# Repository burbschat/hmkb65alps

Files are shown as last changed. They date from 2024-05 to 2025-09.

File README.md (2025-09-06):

# HMKB 65 Alps Compatible PCB and Plate
## Case
* HMKB V1 65 AAA by Heavymetal Keyboards

## Layout
Raw data for [keyboard-layout-editor.com](http://www.keyboard-layout-editor.com):
```json
["~\n`","!\n1","@\n2","#\n3","$\n4","%\n5","^\n6","&\n7","*\n8","(\n9",")\n0","_\n-","+\n=",{w:2},"Backspace",{a:7},""],
[{a:4,w:1.5},"Tab","Q","W","E","R","T","Y","U","I","O","P","{\n[","}\n]",{w:1.5},"|\n\\",{a:7},""],
[{a:4,w:1.75},"Caps Lock","A","S","D","F","G","H","J","K","L",":\n;","\"\n'",{w:2.25},"Enter",{a:7},""],
[{a:4,w:2.25},"Shift","Z","X","C","V","B","N","M","<\n,",">\n.","?\n/",{w:1.75},"Shift",{a:7},"",""],
[{a:4,w:1.25},"Ctrl",{w:1.25},"Win",{w:1.25},"Alt",{a:7,w:6.25},"",{a:4},"Alt","Fn","Ctrl",{a:7},"","",""] 
```
Matrix position annotated version (also without label position information as this messes with scripts using the annotated version down the line):
```json
["0,0","0,1","0,2","0,3","0,4","0,5","0,6","0,7","0,8","0,9","0,10","0,11","0,12",{w:2},"0,13","0,14"],
[{w:1.5},"1,0","1,1","1,2","1,3","1,4","1,5","1,6","1,7","1,8","1,9","1,10","1,11","1,12",{w:1.5},"1,13","1,14"],
[{w:1.75},"2,0","2,1","2,2","2,3","2,4","2,5","2,6","2,7","2,8","2,9","2,10","2,11",{w:2.25},"2,13","2,14"],
[{w:2.25},"3,0","3,1","3,2","3,3","3,4","3,5","3,6","3,7","3,8","3,9","3,10",{w:1.75},"3,12","3,13","3,14"],
[{w:1.25},"4,0",{w:1.25},"4,1",{w:1.25},"4,2",{w:6.25},"4,5","4,9","4,10","4,11","4,12","4,13","4,14"]
```

Find in proper json format in `hmkb65alps.json`.
The corresponding **annotated** (i.e. which key goes where in the matrix) in
[kle-serial](https://github.com/ijprest/kle-serial) format can be found in
`hmkb65alps-annotated_kle-serial.json` (converted using
[this](https://adamws.github.io/kle-serial/)).

## PCB

### Footprints etc.
Included as submodules in `lib/`. 
* [ai03-2725's MX_V2](https://github.com/ai03-2725/MX_V2) for switch footprints
* [ai03-2725's Type-C.pretty](https://github.com/ai03-2725/Type-C.pretty) for USB-C port footprints
* [ai03-2725's random-keyboard-parts.pretty](https://github.com/ai03-2725/random-keyboard-parts.pretty) for USB-C port footprints
The MX_V2 (which also contain ALPS footprints) are fine, the other ones are not
quite to my taste.

#### 3D Models for Key Switches
Found a ALPS switch model [here](https://www.thingiverse.com/thing:3829342/files). 
Very kindly there is an scad file provided (and not just a mesh `.stl` or similar)!

### Components
#### USB-C Connector
All of the options here are selected to be hand solderable.

`Korean Hroparts Elec TYPE-C-31-M-12` Seems to be a popular choice, probably because it's dirt cheap (<20cents).
However, it's not available on DigiKey, Mouser or RS. 

`GCT` offers a series of hand solderable connectors.
[Compare them here](https://gct.co/product-compare/usb/usb4085,usb4105,usb4730,usb4800,usb4215).
Note that `USB4085` is entirely through hole, which however at the same time makes accessing the pins challenging.
For this PCB the accessible D+/D- pins were in the wrong order, which is why a different connector was used.
`USB4105` and `USB4215` seem to be essentially the same, with `USB4215` having some locating plastic pegs on the bottom.
The latter however seems not to be available at the usual vendors, so here `USB4105` is choosen as an slighly less cheap
alternative to the dirt cheep `HRO` mentioned above.
`GCT` also has very well structured documentation and links to footprints and 3d models on their website.

### `kbplacer`
Used this [Kicad Plugin](https://github.com/adamws/kicad-kbplacer) for helping
with schematic/layout generation.
There is also a script `layout2schematic.py` in the repository which was used
to generate the key matrix part of the schematic.
Technically one can also access this when the `kbplacer` python package is
installed with `python -m layout2schematic`, but in this case the dependencies
will not be automatically synchronized. The best way probably is to use a
`hatch` virtual environment. Clone the repo and make sure `hatch` is installed.
The `pyproject.toml` defines a `hatch` virtual environment for the tools. To
create it run `hatch env create tools`. To launch a shell with the environment
activated use `hatch -e tools shell`. One may also just run this right away as
this will create the environment if not present.
Btw. for some reason from the `hatch` environment `pythom -m layout2schematic`
does not seem to work, so run the script from the `tools` directory directly.
See also the [the readme file for the tools](https://github.com/adamws/kicad-kbplacer/blob/master/tools/README.md) for more information.

Note that the input `json` file is not directly what is obtained from the [keyboard layout editor](http://www.keyboard-layout-editor.com)!
Use [https://adamws.github.io/kle-serial](https://adamws.github.io/kle-serial/)
or [keyboard-tools.xyz/kle-converter](http://keyboard-tools.xyz/kle-converter)
(as the main README file notes).
In any case, the layout file must be one where the keys in the keyboard layout
editor are annotated using labels as `row,col` to designate where they will be
in the matrix.
Find annotated layout in `hmkb65alps-annotated.json`

**TLDR**: 
```
cd kicad-kbplacer
hatch run tools:layout2schematic -in ../hmkb65alps-annotated-converted.json -out ../pcb/hmkb65alps-matrix.kicad_sch
```
Creates the base matrix schematic which I then manually edited to fit my
preferences.
I load this as a hierarchical sheet into the main kicad project.
~~As I prefer to not use global labels for the rows/columns, I also manually
replace the global labels with hierarchical labels.~~
**Bad idea as this breaks the net resolving with `kbplacer` it seems :(.**
So global labels it is (I also tried if local labels work, but they dont).
TLDR: Use the matrix as generated by `layout2schematic.py`, no touchy.

#### Generating the layout
If you do not do anything funny to the generated key matrix schematic (like
trying to use hierarchical labels), assigning footprints to all parts, then
importing to the pcb layout and running the plugin should just work.

I first assign 1U switches to all of the switches, have them placed and then
adjust the longer ones (way easier than trying to figure out which switch was
where in the matrix.)

When running the plugin point *Keyboard layout file* to
`../hmkb65alps-annotated-converted.json` (or wherever the layout in the correct
format is).
With the MX-Alps hybrid footprints the diode position must be adjusted, as
otherwise it is too close to the holes in the PCB which is not good to begin
with and also will cause the automatic routing to fail.
In *Switch diodes setting* set *Position* to *Custom*. I Chose *Offset X =
7.5*, *Offset Y = -6.5*, *Orientation = -90* and *Side = back*.

Probably better use the *Relative* mode. This will result in the layout for the
first switch being replicated to the others. For some reason this however does
not seem to work for open ended tracks.

### Ideas
* Consider using chips containing multiple diodes in the same package to avoid soldering pain
    * Did not end up prusuing this
* Use Alps/MX hybrid footprints
    * Implemented!
* Consider Alps/MX hybrid plate
    * Can work but probably a bad idea as contact area of switches to plate will be very small
* Mill-Max Sockets for hot-swapping (should also work with hybrid footprints as seen in the pictures [here](https://blog.keeb.io/how-to-make-your-keyboard-hotswappable-with-mill-max-sockets/)).
    * Tried this one. The pins on Alps switches do not play nice with such sockets (they are wider than MX ones requiring quite large sockets)

## Plate
### Design
[ai03 Plate Generator](https://kbplate.ai03.com/) seems to be a well made modern solution (repository [here](https://github.com/ai03-2725/yet-another-keyboard-builder))!
Probably prefer using this over [what used to be the standard tool(?)](http://builder.swillkb.com/) to get plate hole locations
(select no outline, as the correct one is not available there), then manually
add the correct outline from the MX plate files distributed on the HMKB
discord.

**Holdup**, on closer inspection `swillkb` seems to provide [much more features](http://builder-docs.swillkb.com/features/)!
In fact one can adjust the stabilizers for specific keys using special attributes in the layout definition.
This one for example overrides the spacebar stabilizer to be of Cherry + Costar type by using `{a:7,w:6.25, _s:1}`.
```
["~\n`","!\n1","@\n2","#\n3","$\n4","%\n5","^\n6","&\n7","*\n8","(\n9",")\n0","_\n-","+\n=",{w:2},"Backspace",{a:7},""],
[{a:4,w:1.5},"Tab","Q","W","E","R","T","Y","U","I","O","P","{\n[","}\n]",{w:1.5},"|\n\\",{a:7},""],
[{a:4,w:1.75},"Caps Lock","A","S","D","F","G","H","J","K","L",":\n;","\"\n'",{w:2.25},"Enter",{a:7},""],
[{a:4,w:2.25},"Shift","Z","X","C","V","B","N","M","<\n,",">\n.","?\n/",{w:1.75},"Shift",{a:7},"",""],
[{a:4,w:1.25},"Ctrl",{w:1.25},"Win",{w:1.25},"Alt",{a:7,w:6.25, _s:1},"",{a:4},"Alt","Fn","Ctrl",{a:7},"","",""]
```
This is exactly what I need for the Tai-Hao Keycaps which have cherry type stabilizers on only the spacebar.
Seems like one can also further [specify the outline](http://builder-docs.swillkb.com/features/#custom-polygons).
If possible, defining the whole plate programatically would be cool.
Actually, we could get away without using the web interface alltogether by using [`KAD`](https://github.com/swill/kad),
the library powering [builder.swillkb.com](http://builder.swillkb.com/).

**Holdup**, but `swillkb` does not do rounded corners as I might need for a PCB plate.
So I forked ai03 Plate Generator (aka yet-another-keyboard-builder) and 
[modified the code](https://github.com/burbschat/yet-another-keyboard-builder/tree/key_specific_overrides) 
with my essentially non existent javascript knowledge, which actually worked!
It's probably not pretty or good practice though, but good enough for what I need for now.

Here is the layout that should fit for stabiliziers for the Tai-Hao Alps keycaps:
```
["~\n`","!\n1","@\n2","#\n3","$\n4","%\n5","^\n6","&\n7","*\n8","(\n9",")\n0","_\n-","+\n=",{w:2},"Backspace",{a:7},""],
[{a:4,w:1.5},"Tab","Q","W","E","R","T","Y","U","I","O","P","{\n[","}\n]",{w:1.5},"|\n\\",{a:7},""],
[{a:4,w:1.75},"Caps Lock","A","S","D","F","G","H","J","K","L",":\n;","\"\n'",{w:2.25},"Enter",{a:7},""],
[{a:4,w:2.25},"Shift","Z","X","C","V","B","N","M","<\n,",">\n.","?\n/",{w:1.75},"Shift",{a:7},"",""],
[{a:4,w:1.25},"Ctrl",{w:1.25},"Win",{w:1.25},"Alt",{a:7,w:6.25, _s:"mx-basic"},"",{a:4},"Alt","Fn","Ctrl",{a:7},"","",""]
```

I also generated the plate with flipped Alps stabilizers as 
```
["~\n`","!\n1","@\n2","#\n3","$\n4","%\n5","^\n6","&\n7","*\n8","(\n9",")\n0","_\n-","+\n=",{w:2,_rs:180},"Backspace",{a:7},""],
[{a:4,w:1.5},"Tab","Q","W","E","R","T","Y","U","I","O","P","{\n[","}\n]",{w:1.5},"|\n\\",{a:7},""],
[{a:4,w:1.75,_rs:180},"Caps Lock","A","S","D","F","G","H","J","K","L",":\n;","\"\n'",{w:2.25,_rs:180},"Enter",{a:7},""],
[{a:4,w:2.25,_rs:180},"Shift","Z","X","C","V","B","N","M","<\n,",">\n.","?\n/",{w:1.75,_rs:180},"Shift",{a:7},"",""],
[{a:4,w:1.25},"Ctrl",{w:1.25},"Win",{w:1.25},"Alt",{a:7,w:6.25, _s:"mx-basic"},"",{a:4},"Alt","Fn","Ctrl",{a:7},"","",""]
```
and `alps-aek` instead of `mx-basic` for the spacebar which I then all composed in KiCad, which was possible
as the cutouts do not overlap.
This means that I do not have to worry about the orientation of the stabilizers (some Tai-Hao keycaps 
seem to have them inversed) and can later decide if I want alps or Cherry stabilizers on the spacebar 
(Tai-Hao keycaps support those on only the spacebar but there seem to also be adapters to use Alps stabilizers).

### Material
* Try lasercutting ~1.6mm plate on the lasercutter that is avaiable at my
university (even though it is not rated to cut metal this thick)?
    * Have to source metal plates which might not be cheap in small quantities
    * Not pursued eventually.
* Order FR4 plate (i.e. just a PCB). This seems to be very reasonably priced.
Getting FR4 stock cheaper and cutting on the lasercutter appeared difficult
(could not find very cheap FR4 stock).
    * Ordering a PCB in plate size seems to cost around 3000JPY. One could also
    get an aluminum PCB for just a little more, but I don't know if an aluminum
    plate is a good idea. FR4 appeared much more sturdy to me but I did not
    make a direct comparison.
    * This is the eventually adopted option

## References
* [Masterzen's blog](https://www.masterzen.fr/2020/05/03/designing-a-keyboard-part-1/) (multiple parts)
* Artwork on the PCB is Comet from [Higgs-Tan](https://higgstan.com/)

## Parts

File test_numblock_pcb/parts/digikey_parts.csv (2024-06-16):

索引 | 数量 | 品番 | メーカー品番 | 商品概要 | 客先参照品番 | 入手可能 | 繰越注文 | 単価 | 合計金額 JPY
1 | 10 | 1727-3884-1-ND | PRTR5V0U2X,215 | TVS DIODE 5.5VWM SOT143B | 1 | 10 | 0 | 57.90000 | 579
2 | 2 | ATMEGA32U4-AU-ND | ATMEGA32U4-AU | IC MCU 8BIT 32KB FLASH 44TQFP | 2 | 2 | 0 | 885.00000 | 1,770
3 | 10 | 2073-USB4105-GF-A-120CT-ND | USB4105-GF-A-120 | CONN RCP USB2.0 TYP C 24P SMD RA | 3 | 10 | 0 | 115.10000 | 1,151
4 | 5 | 4809-SKQGADE010CT-ND | SKQGADE010 | SWITCH TACTILE SPST-NO 0.05A 12V | 4 | 5 | 0 | 104.00000 | 520
5 | 5 | SER4069CT-ND | TSX-3225 16.0000MF09Z-AC0 | CRYSTAL 16.0000MHZ 9PF SMD | 5 | 5 | 0 | 70.00000 | 350
6 | 10 | 507-1799-1-ND | 0ZCJ0025AF2E | PTC RESET FUSE 24V 250MA 1206 | 6 | 10 | 0 | 24.60000 | 246
7 | 10 | 54-3305-1-15-80-47-27-10-0-ND | 3305-1-15-80-47-27-10-0 | .130" LONG RECEPTACLE; ACCEPTS . | 7 | 10 | 0 | 67.10000 | 671
8 | 10 | ED90584-ND | 0305-2-15-80-47-80-10-0 | CONN PIN RCPT .025-.037 SOLDER |  | 10 | 0 | 33.30000 | 333
9 | 10 | A122922-ND | 9-1437514-0 | CONN PIN RCPT .016-.021 PRESSFIT |  | 10 | 0 | 42.10000 | 421

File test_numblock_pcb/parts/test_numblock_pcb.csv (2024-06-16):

Id | Designator | Footprint | Quantity | Designation | Supplier | Supplier Ref | Quantity Ordered | Supplier Description | Comment | Cost
1 | SW6,SW2,SW10,SW9,SW12,SW1,SW17,SW4,SW3,SW5,SW14,SW7,SW11,SW13 | MX-Alps-Hybrid-1U | 14 | SW_Push
2 | C3,C7,C4,C2 | C_0805_2012Metric_Pad1.18x1.45mm_HandSolder | 4 | 0.1uF | RS | 648-0941 | 60 | KEMET 積層セラミックコンデンサ(MLCC) 100nF 50V dc 0805 (2012M) C0805C104J5RACTU |  | 150
3 | C8 | C_0805_2012Metric_Pad1.18x1.45mm_HandSolder | 1 | 1uF | RS | 134-9148 | 100 | KYOCERA AVX 積層セラミックコンデンサ(MLCC) 1μF 16V dc 0805 (2012M) 0805YG105ZAT2A |  | 250
4 | SW8,SW15,SW16 | MX-Alps-Hybrid-2U | 3 | SW_Push
5 | R6,R1 | R_0805_2012Metric_Pad1.20x1.40mm_HandSolder | 2 | 10k | RS | 223-0556, 223-0578 | 50 | TE Connectivity 厚膜チップ抵抗器, 2012サイズ, 0.125W, 8.2kΩ, ±1%, TE Connectivity 厚膜チップ抵抗器, 2012サイズ, 0.125W, 12kΩ, ±1% | Ordered 8.2k AND 12k as closest available values (61+61jpy) | 122
6 | R2,R3 | R_0805_2012Metric_Pad1.20x1.40mm_HandSolder | 2 | 5.1k | RS | 223-0528 | 50 | TE Connectivity 厚膜チップ抵抗器, 2012サイズ, 0.125W, 4.7kΩ, ±1% | Ordered 4.7k as closest available value | 189
7 | C1 | C_0805_2012Metric_Pad1.18x1.45mm_HandSolder | 1 | 10uF | RS | 240-5703 | 50 | 太陽誘電 MLCC 10μF 10V dc 0805 (2012M) MSASL21GAB7106KTNA01 |  | 398
8 | D12,D1,D5,D7,D13,D2,D10,D9,D17,D14,D8,D4,D16,D3,D11,D6,D15 | D_SOD-123 | 17 | D | RS | 791-6167 | 200 | onsemi 小信号 整流ダイオード, 200mA, 250V 表面実装, 2-Pin SOD-123 シリコンジャンクション 1.25V |  | 1742
9 | U1 | TQFP-44_10x10mm_P0.8mm | 1 | ATmega32U4-A | DigiKey | ATMEGA32U4-AU-ND | 3 | IC MCU 8BIT 32KB FLASH 44TQFP |  | 2655
10 | D18 | SOT-143 | 1 | PRTR5V0U2X | DigiKey | 1727-3884-1-ND | 10 | TVS DIODE 5.5VWM SOT143B |  | 579
11 | R5,R4 | R_0805_2012Metric_Pad1.20x1.40mm_HandSolder | 2 | 22 | RS | 223-0203 | 50 | TE Connectivity 厚膜チップ抵抗器, 2012サイズ, 0.125W, 22Ω, ±1% |  | 61
12 | J2 | GCT_USB4105GFA120 | 1 | USB4105GFA120 | DigiKey | 2073-USB4105-GF-A-120CT-ND | 10 | CONN RCP USB2.0 TYP C 24P SMD RA |  | 1151
13 | F1 | Fuse_1206_3216Metric_Pad1.42x1.75mm_HandSolder | 1 | 500m | DigiKey | 507-1799-1-ND | 10 | PTC RESET FUSE 24V 250MA 1206 |  | 246
14 | SW18 | SW_SPST_SKQG_WithStem | 1 | SW_Push | DigiKey | 4809-SKQGADE010CT-ND | 5 | SWITCH TACTILE SPST-NO 0.05A 12V |  | 520
15 | C6,C5 | C_0805_2012Metric_Pad1.18x1.45mm_HandSolder | 2 | 22pF | RS | 264-4258 | 25 | KEMET 積層セラミックコンデンサ(MLCC) 22pF 50V dc 0805 (2012M) C0805C220J5GACTU |  | 110
16 | J1 | PinHeader_2x03_P2.54mm_Vertical | 1 | AVR-ISP-6
17 | Y1 | Crystal_SMD_3225-4Pin_3.2x2.5mm_HandSoldering | 1 | 16MHz | DigiKey | SER4069CT-ND | 5 | CRYSTAL 16.0000MHZ 9PF SMD |  | 350
 |  |  |  |  | DigiKey | 54-3305-1-15-80-47-27-10-0-ND | 10 | Mill-Max Manufacturing Corp. .130" LONG RECEPTACLE; ACCEPTS . |  | 671
 |  |  |  |  | DigiKey | ED90584-ND | 10 | Mill-Max Manufacturing Corp. CONN PIN RCPT .025-.037 SOLDER |  | 333
 |  |  |  |  |  |  |  |  | SUM（税抜き）: | 9527

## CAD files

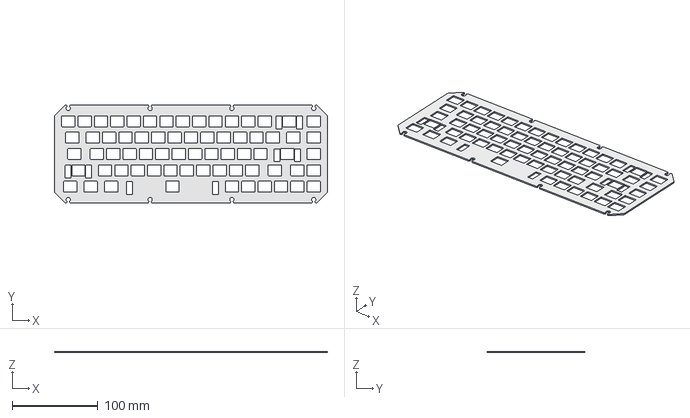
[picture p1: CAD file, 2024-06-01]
plate/plate_merged.FCStd
317.7 x 114.6 x 1.60 mm

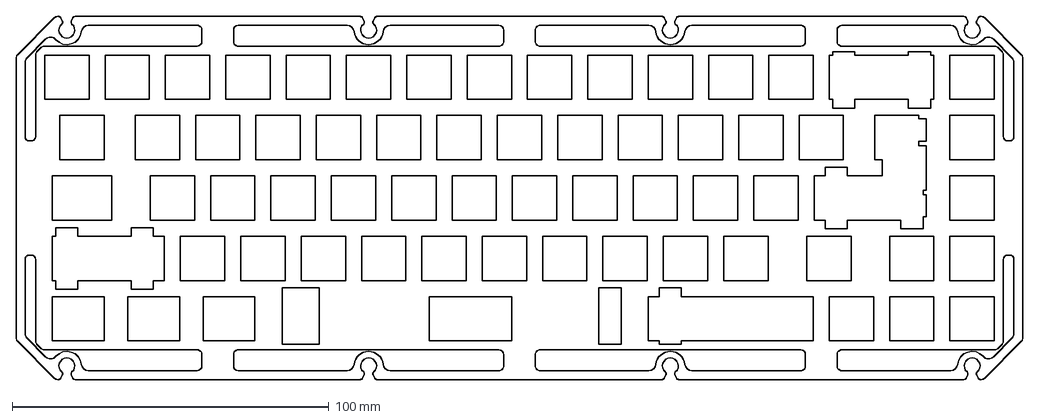
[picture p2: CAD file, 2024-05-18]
plate/reference/HMKB-65-PLT-UNI.dxf
317.7 x 114.6 mm

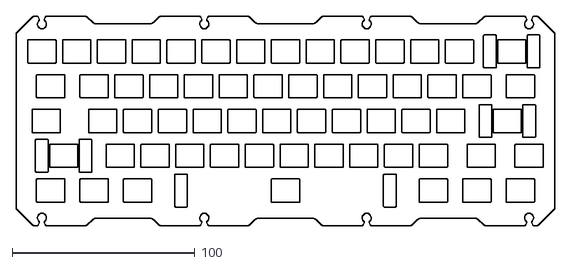
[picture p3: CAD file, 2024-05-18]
plate/reference/HMKB-60-PLT-TSAN-ALPS-FR4.dxf
294.8 x 114.6

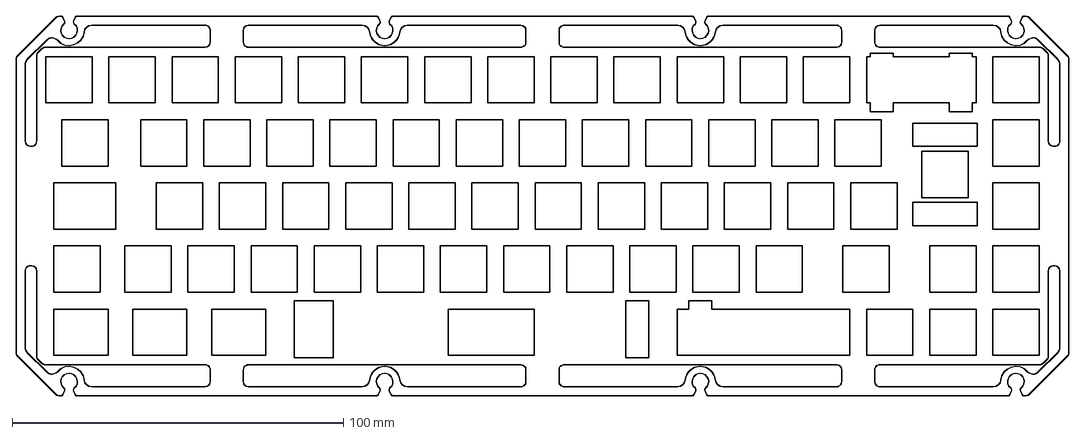
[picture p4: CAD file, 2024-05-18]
plate/reference/HMKB-65-PLT-ISO.dxf
317.7 x 114.6 mm

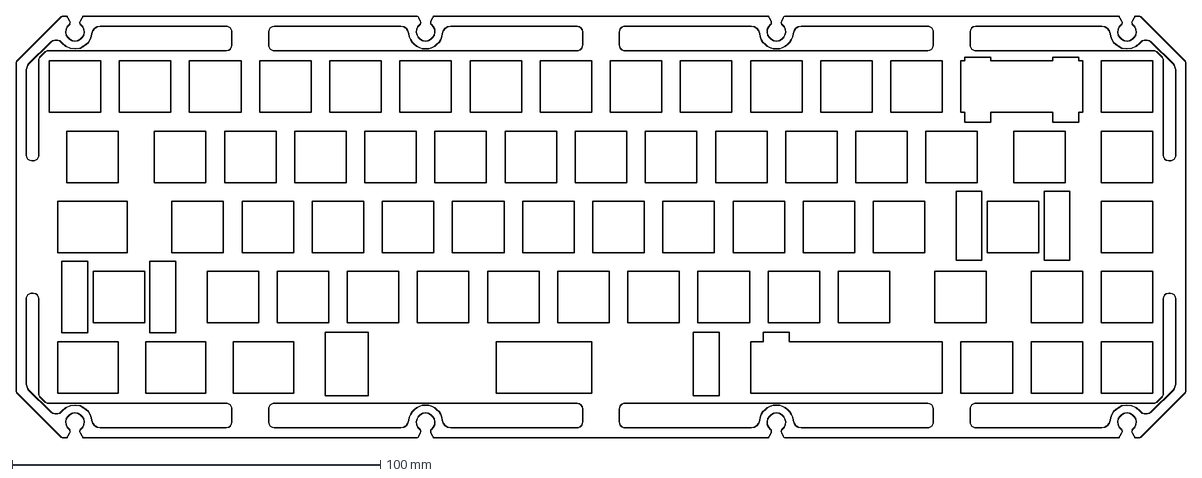
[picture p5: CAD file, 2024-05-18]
plate/reference/HMKB-65-PLT-ANSI.dxf
317.7 x 114.6 mm

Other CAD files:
test_numblock_case/test_numblock_case.FCStd
plate/plate_merged.dxf

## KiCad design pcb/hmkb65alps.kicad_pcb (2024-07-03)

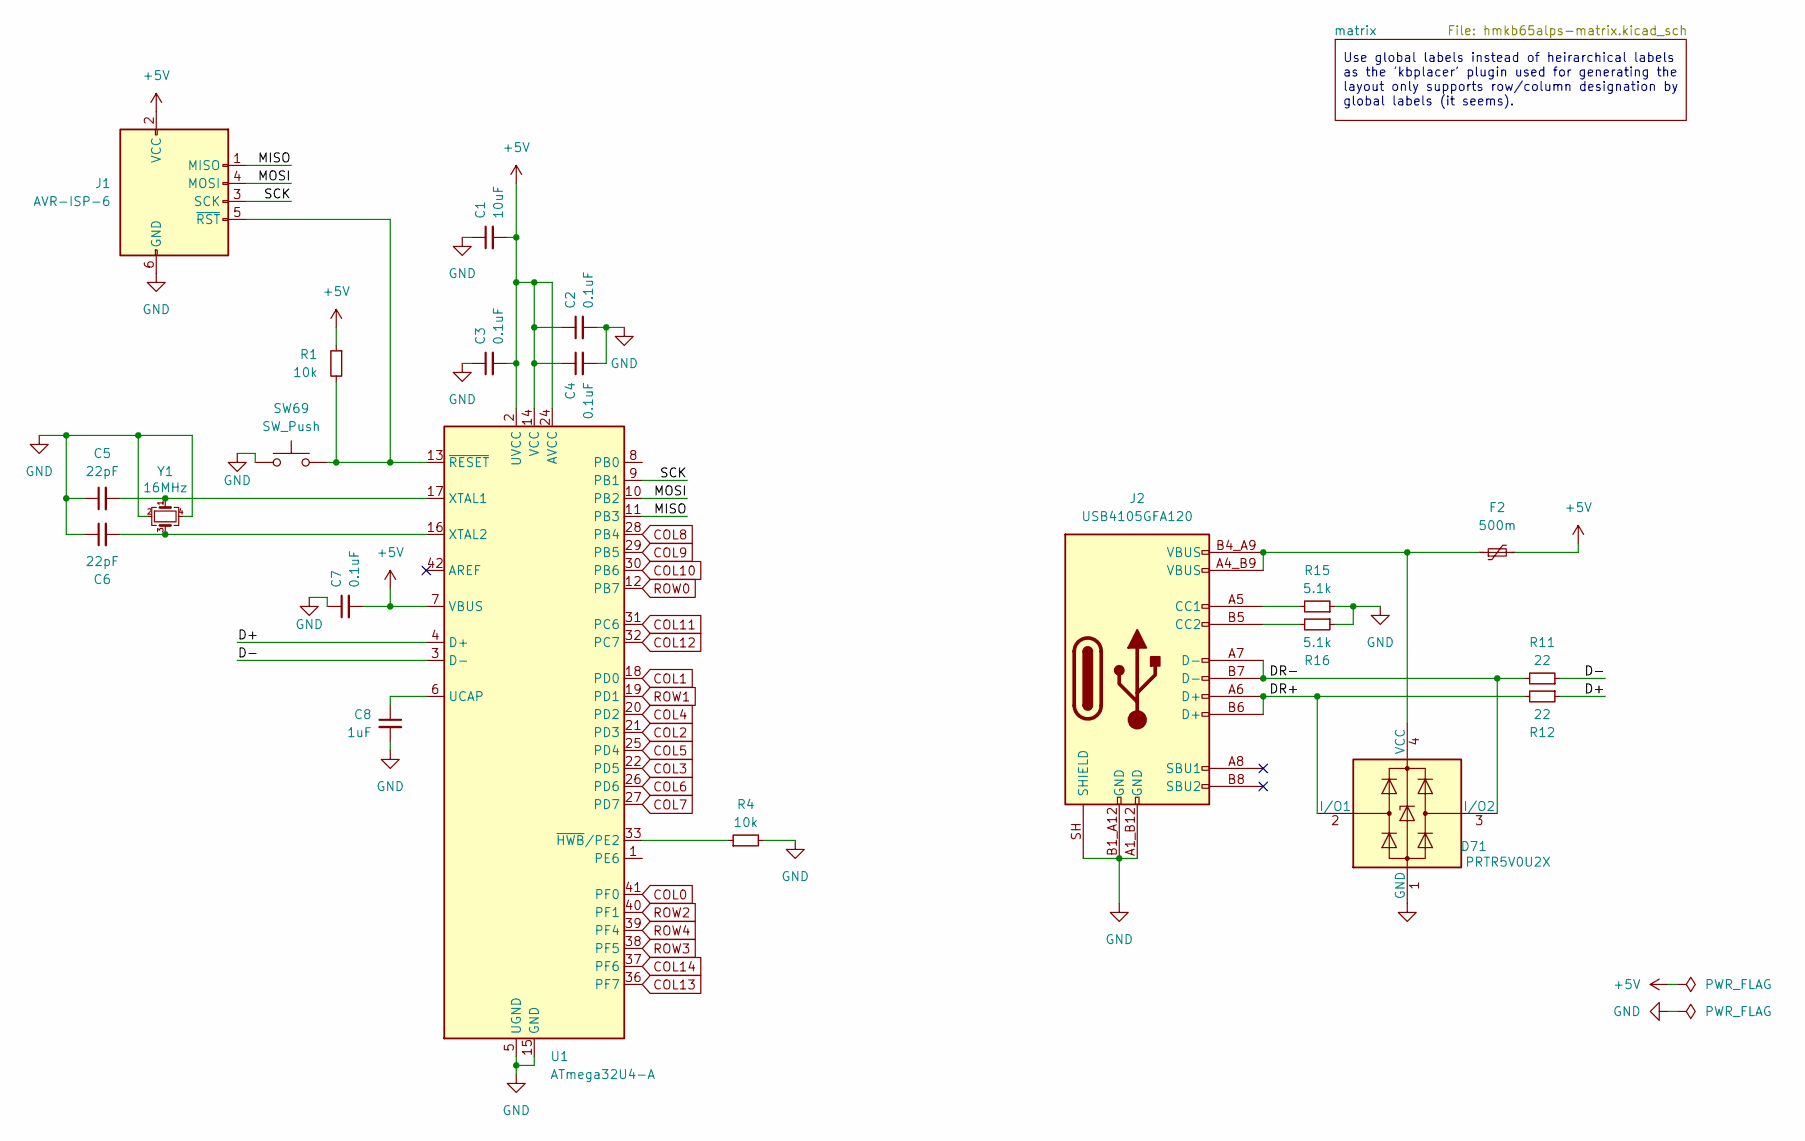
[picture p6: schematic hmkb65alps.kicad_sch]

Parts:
C1: 10uF; C_0805_2012Metric_Pad1.18x1.45mm_HandSolder
C2, C3, C4, C7: 0.1uF; C_0805_2012Metric_Pad1.18x1.45mm_HandSolder
C5, C6: 22pF; C_0805_2012Metric_Pad1.18x1.45mm_HandSolder
C8: 1uF; C_0805_2012Metric_Pad1.18x1.45mm_HandSolder
D71: PRTR5V0U2X; SOT-143
F2: 500m; Fuse_1206_3216Metric_Pad1.42x1.75mm_HandSolder
J1: AVR-ISP-6; IDC-Header_2x03_P2.54mm_Vertical
J2: USB4105GFA120; GCT_USB4105GFA120
R1, R4: 10k; R_0805_2012Metric_Pad1.20x1.40mm_HandSolder
R11, R12: 22; R_0805_2012Metric_Pad1.20x1.40mm_HandSolder
R15, R16: 5.1k; R_0805_2012Metric_Pad1.20x1.40mm_HandSolder
SW69: SW_Push; SW_SPST_SKQG_WithStem
U1: ATmega32U4-A; TQFP-44_10x10mm_P0.8mm
Y1: 16MHz; Crystal_SMD_3225-4Pin_3.2x2.5mm_HandSoldering

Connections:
+5V: C1.2, C2.1, C3.2, C4.1, C7.2, F2.2, J1.2 (VCC), R1.1, U1.2 (UVCC), U1.7 (VBUS), U1.14 (VCC), U1.24 (AVCC), U1.34 (VCC), U1.44 (AVCC)
/D+: R12.1, U1.4 (D+)
/D-: R11.1, U1.3 (D-)
/DR+: D71.2 (I/O1), J2.A6 (D+), J2.B6 (D+), R12.2
/DR-: D71.3 (I/O2), J2.A7 (D-), J2.B7 (D-), R11.2
/MISO: J1.1 (MISO), U1.11 (PB3)
/MOSI: J1.4 (MOSI), U1.10 (PB2)
/SCK: J1.3 (SCK), U1.9 (PB1)
COL0: U1.41 (PF0); also elsewhere on the board
COL1: U1.18 (PD0); also elsewhere on the board
COL2: U1.21 (PD3); also elsewhere on the board
COL3: U1.22 (PD5); also elsewhere on the board
COL4: U1.20 (PD2); also elsewhere on the board
COL5: U1.25 (PD4); also elsewhere on the board
COL6: U1.26 (PD6); also elsewhere on the board
COL7: U1.27 (PD7); also elsewhere on the board
COL8: U1.28 (PB4); also elsewhere on the board
COL9: U1.29 (PB5); also elsewhere on the board
COL10: U1.30 (PB6); also elsewhere on the board
COL11: U1.31 (PC6); also elsewhere on the board
COL12: U1.32 (PC7); also elsewhere on the board
COL13: U1.36 (PF7); also elsewhere on the board
COL14: U1.37 (PF6); also elsewhere on the board
GND: C1.1, C2.2, C3.1, C4.2, C5.1, C6.1, C7.1, C8.2, D71.1 (GND), J1.6 (GND), J2.A1_B12 (GND), J2.B1_A12 (GND), J2.SH (SHIELD), R4.2, R15.1, R16.1, SW69.1, U1.5 (UGND), U1.15 (GND), U1.23 (GND), U1.35 (GND), U1.43 (GND), Y1.2, Y1.4
unnamed: D71.4 (VCC), F2.1, J2.A4_B9 (VBUS), J2.B4_A9 (VBUS)
unnamed: J1.5 (~RST), R1.2, SW69.2, U1.13 (~RESET)
unnamed: J2.A5 (CC1), R15.2
unnamed: J2.B5 (CC2), R16.2
unnamed: C8.1, U1.6 (UCAP)
unnamed: C5.2, U1.17 (XTAL1), Y1.1
unnamed: C6.2, U1.16 (XTAL2), Y1.3
unnamed: R4.1, U1.33 (~HWB/PE2)
ROW0: U1.12 (PB7); also elsewhere on the board
ROW1: U1.19 (PD1); also elsewhere on the board
ROW2: U1.40 (PF1); also elsewhere on the board
ROW3: U1.38 (PF5); also elsewhere on the board
ROW4: U1.39 (PF4); also elsewhere on the board

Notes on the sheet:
Use global labels instead of heirarchical labels as the 'kbplacer' plugin used for generating the layout only supports row/column designation by global labels (it seems).

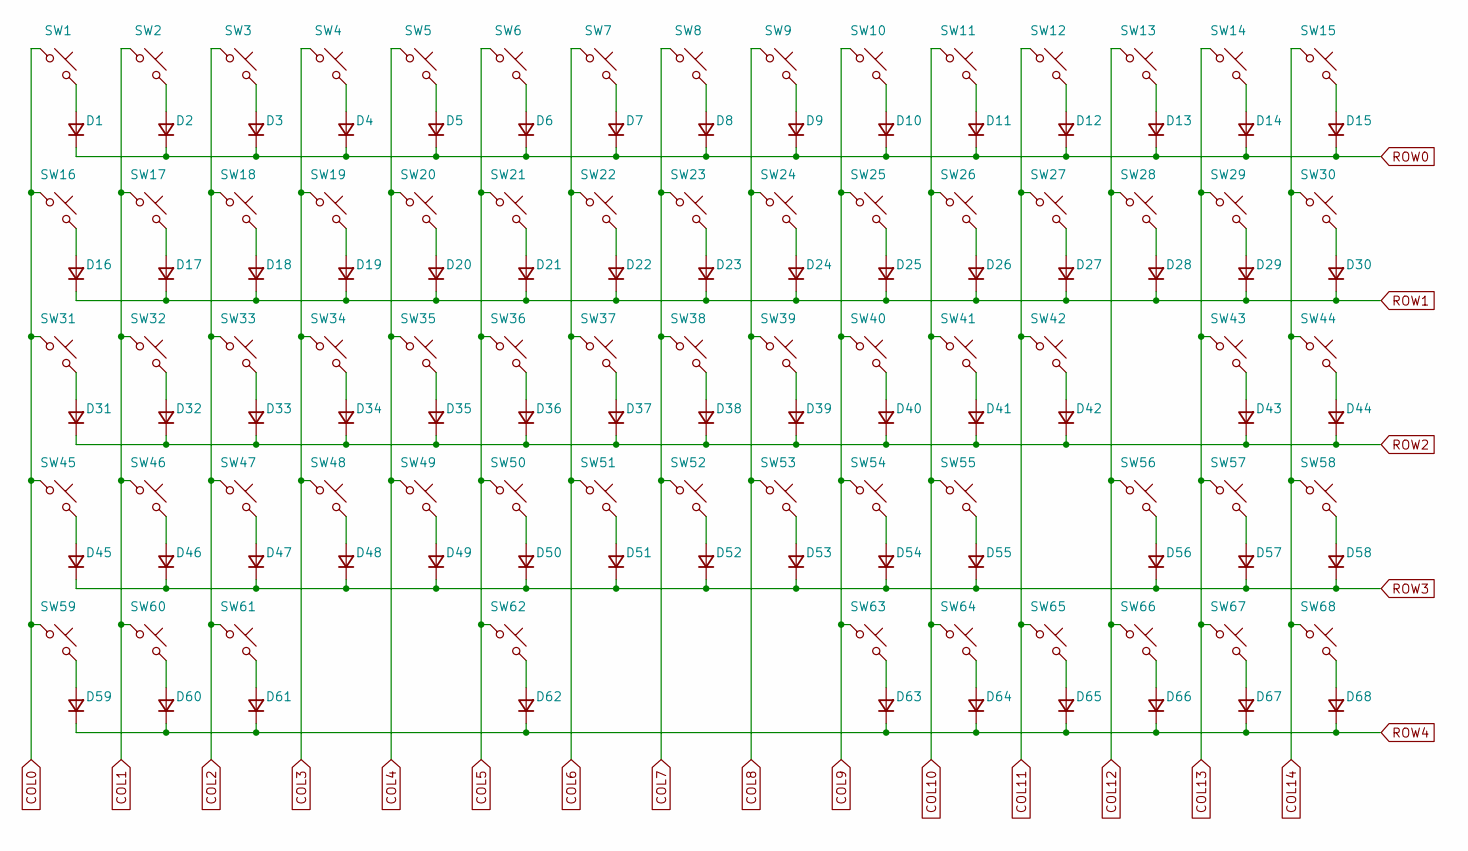
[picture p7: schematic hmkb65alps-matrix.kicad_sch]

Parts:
D1, D2, D3, D4, D5, D6, D7, D8, D9, D10, D11, D12, D13, D14, D15, D16, D17, D18, D19, D20, D21, D22, D23, D24, D25, D26, D27, D28, D29, D30, D31, D32, D33, D34, D35, D36, D37, D38, D39, D40, D41, D42, D43, D44, D45, D46, D47, D48, D49, D50, D51, D52, D53, D54, D55, D56, D57, D58, D59, D60, D61, D62, D63, D64, D65, D66, D67, D68: D; D_SOD-123
SW1, SW2, SW3, SW4, SW5, SW6, SW7, SW8, SW9, SW10, SW11, SW12, SW13, SW15, SW17, SW18, SW19, SW20, SW21, SW22, SW23, SW24, SW25, SW26, SW27, SW28, SW30, SW32, SW33, SW34, SW35, SW36, SW37, SW38, SW39, SW40, SW41, SW42, SW44, SW46, SW47, SW48, SW49, SW50, SW51, SW52, SW53, SW54, SW55, SW57, SW58, SW63, SW64, SW65, SW66, SW67, SW68: SW_Push; MX-Alps-Hybrid-1U
SW14: SW_Push; MX-Alps-Hybrid-2U
SW16, SW29: SW_Push; MX-Alps-Hybrid-1.5U
SW31, SW56: SW_Push; MX-Alps-Hybrid-1.75U
SW43, SW45: SW_Push; MX-Alps-Hybrid-2.25U
SW59, SW60, SW61: SW_Push; MX-Alps-Hybrid-1.25U
SW62: SW_Push; MX-Alps-Hybrid-6.25U

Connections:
COL0: SW1.1, SW16.1, SW31.1, SW45.1, SW59.1; also elsewhere on the board
COL1: SW2.1, SW17.1, SW32.1, SW46.1, SW60.1; also elsewhere on the board
COL2: SW3.1, SW18.1, SW33.1, SW47.1, SW61.1; also elsewhere on the board
COL3: SW4.1, SW19.1, SW34.1, SW48.1; also elsewhere on the board
COL4: SW5.1, SW20.1, SW35.1, SW49.1; also elsewhere on the board
COL5: SW6.1, SW21.1, SW36.1, SW50.1, SW62.1; also elsewhere on the board
COL6: SW7.1, SW22.1, SW37.1, SW51.1; also elsewhere on the board
COL7: SW8.1, SW23.1, SW38.1, SW52.1; also elsewhere on the board
COL8: SW9.1, SW24.1, SW39.1, SW53.1; also elsewhere on the board
COL9: SW10.1, SW25.1, SW40.1, SW54.1, SW63.1; also elsewhere on the board
COL10: SW11.1, SW26.1, SW41.1, SW55.1, SW64.1; also elsewhere on the board
COL11: SW12.1, SW27.1, SW42.1, SW65.1; also elsewhere on the board
COL12: SW13.1, SW28.1, SW56.1, SW66.1; also elsewhere on the board
COL13: SW14.1, SW29.1, SW43.1, SW57.1, SW67.1; also elsewhere on the board
COL14: SW15.1, SW30.1, SW44.1, SW58.1, SW68.1; also elsewhere on the board
unnamed: D1.2 (A), SW1.2
unnamed: D2.2 (A), SW2.2
unnamed: D3.2 (A), SW3.2
unnamed: D4.2 (A), SW4.2
unnamed: D5.2 (A), SW5.2
unnamed: D6.2 (A), SW6.2
unnamed: D7.2 (A), SW7.2
unnamed: D8.2 (A), SW8.2
unnamed: D9.2 (A), SW9.2
unnamed: D10.2 (A), SW10.2
unnamed: D11.2 (A), SW11.2
unnamed: D12.2 (A), SW12.2
unnamed: D13.2 (A), SW13.2
unnamed: D14.2 (A), SW14.2
unnamed: D15.2 (A), SW15.2
unnamed: D16.2 (A), SW16.2
unnamed: D17.2 (A), SW17.2
unnamed: D18.2 (A), SW18.2
unnamed: D19.2 (A), SW19.2
unnamed: D20.2 (A), SW20.2
unnamed: D21.2 (A), SW21.2
unnamed: D22.2 (A), SW22.2
unnamed: D23.2 (A), SW23.2
unnamed: D24.2 (A), SW24.2
unnamed: D25.2 (A), SW25.2
unnamed: D26.2 (A), SW26.2
unnamed: D27.2 (A), SW27.2
unnamed: D28.2 (A), SW28.2
unnamed: D29.2 (A), SW29.2
unnamed: D30.2 (A), SW30.2
unnamed: D31.2 (A), SW31.2
unnamed: D32.2 (A), SW32.2
unnamed: D33.2 (A), SW33.2
unnamed: D34.2 (A), SW34.2
unnamed: D35.2 (A), SW35.2
unnamed: D36.2 (A), SW36.2
unnamed: D37.2 (A), SW37.2
unnamed: D38.2 (A), SW38.2
unnamed: D39.2 (A), SW39.2
unnamed: D40.2 (A), SW40.2
unnamed: D41.2 (A), SW41.2
unnamed: D42.2 (A), SW42.2
unnamed: D43.2 (A), SW43.2
unnamed: D44.2 (A), SW44.2
unnamed: D45.2 (A), SW45.2
unnamed: D46.2 (A), SW46.2
unnamed: D47.2 (A), SW47.2
unnamed: D48.2 (A), SW48.2
unnamed: D49.2 (A), SW49.2
unnamed: D50.2 (A), SW50.2
unnamed: D51.2 (A), SW51.2
unnamed: D52.2 (A), SW52.2
unnamed: D53.2 (A), SW53.2
unnamed: D54.2 (A), SW54.2
unnamed: D55.2 (A), SW55.2
unnamed: D56.2 (A), SW56.2
unnamed: D57.2 (A), SW57.2
unnamed: D58.2 (A), SW58.2
unnamed: D59.2 (A), SW59.2
unnamed: D60.2 (A), SW60.2
unnamed: D61.2 (A), SW61.2
unnamed: D62.2 (A), SW62.2
unnamed: D63.2 (A), SW63.2
unnamed: D64.2 (A), SW64.2
unnamed: D65.2 (A), SW65.2
unnamed: D66.2 (A), SW66.2
unnamed: D67.2 (A), SW67.2
unnamed: D68.2 (A), SW68.2
ROW0: D1.1 (K), D2.1 (K), D3.1 (K), D4.1 (K), D5.1 (K), D6.1 (K), D7.1 (K), D8.1 (K), D9.1 (K), D10.1 (K), D11.1 (K), D12.1 (K), D13.1 (K), D14.1 (K), D15.1 (K); also elsewhere on the board
ROW1: D16.1 (K), D17.1 (K), D18.1 (K), D19.1 (K), D20.1 (K), D21.1 (K), D22.1 (K), D23.1 (K), D24.1 (K), D25.1 (K), D26.1 (K), D27.1 (K), D28.1 (K), D29.1 (K), D30.1 (K); also elsewhere on the board
ROW2: D31.1 (K), D32.1 (K), D33.1 (K), D34.1 (K), D35.1 (K), D36.1 (K), D37.1 (K), D38.1 (K), D39.1 (K), D40.1 (K), D41.1 (K), D42.1 (K), D43.1 (K), D44.1 (K); also elsewhere on the board
ROW3: D45.1 (K), D46.1 (K), D47.1 (K), D48.1 (K), D49.1 (K), D50.1 (K), D51.1 (K), D52.1 (K), D53.1 (K), D54.1 (K), D55.1 (K), D56.1 (K), D57.1 (K), D58.1 (K); also elsewhere on the board
ROW4: D59.1 (K), D60.1 (K), D61.1 (K), D62.1 (K), D63.1 (K), D64.1 (K), D65.1 (K), D66.1 (K), D67.1 (K), D68.1 (K); also elsewhere on the board

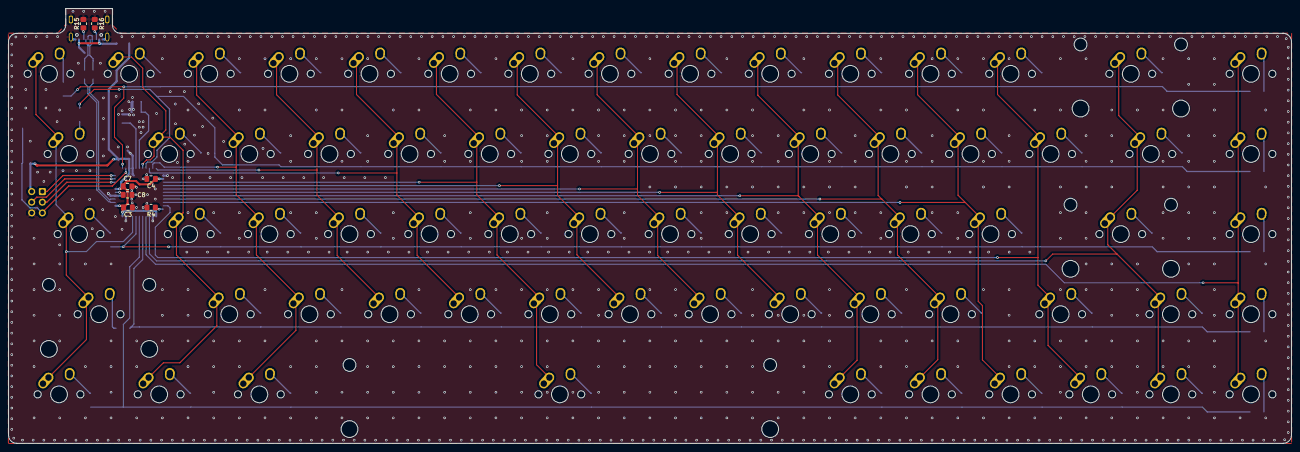
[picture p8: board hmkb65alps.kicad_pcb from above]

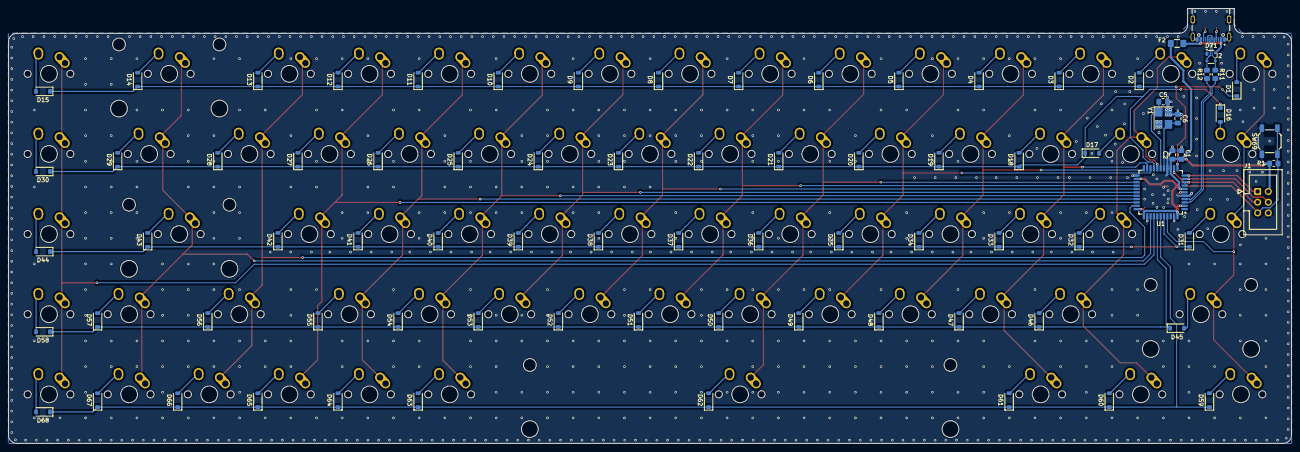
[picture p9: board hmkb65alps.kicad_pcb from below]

Board: 2 copper layers, 305.0 x 103.4 mm, 157 parts (82 on the bottom side), 105 nets.

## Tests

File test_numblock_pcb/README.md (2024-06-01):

# Numblock PCB for testing before ordering a larger pcb

## Layout
```
["Num Lock","/","*","-"],
["7\nHome","8\n↑","9\nPgUp",{h:2},"+"],
["4\n←","5","6\n→"],
["1\nEnd","2\n↓","3\nPgDn",{h:2},"Enter"],
[{w:2},"0\nIns",".\nDel"]
```

Layout with matrix position labels for matrix schematic generation using kicad-kbplacer:
```
["1,1","1,2","1,3","1,4"],
["2,1","2,2","2,3",{h:2},"2,4"],
["3,1","3,2","3,3"],
["4,1","4,2","4,3",{h:2},"4,4"],
[{w:2},"5,1","5,3"]
```

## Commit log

2024-05-26 add submodules for switch and usb-c footprints
2024-05-26 create kicad project for pcb
    also add some of the possibly useful footprint libraries to the library
    table
    [hmkb64alps.kicad_pcb, hmkb64alps.kicad_sch]
2024-05-26 add symbol libraries and further footprint library to tables
2024-05-26 draw mcu schematic
    [hmkb64alps.kicad_sch]
2024-05-26 add usb-c and ISP to mcu schematic
    [hmkb64alps.kicad_sch]
2024-05-26 add key key matrix to schematic
    [hmkb64alps-matrix.kicad_sch, hmkb64alps.kicad_sch]
2024-05-26 revert to global labels for matrix
    kbplacer does unfortunately not seem to work with local or hierarchical
    labels (which I would have prefered). So global labels it is.
    Essentially that means using the schematic generated by
    `layout2schematic.py` works fine and best.
    [hmkb64alps-matrix.kicad_sch, hmkb64alps.kicad_sch]
2024-05-26 define net classes and corresponding track widths
    [hmkb64alps.kicad_pcb, hmkb64alps.kicad_sch]
2024-05-26 assign correct switch footprints to all switches
    [hmkb64alps-matrix.kicad_sch]
2024-05-26 place switches and set some design rules
    [hmkb64alps.kicad_pcb]
2024-05-26 fix manually where the kbplace autorouter failed
    [hmkb64alps.kicad_pcb]
2024-05-26 add missing values for oscillator capacitors
    [hmkb64alps.kicad_sch]
2024-05-26 sort of arrange the mcu related components
    need to get the pcb outline next to do proper positioning.
    [hmkb64alps.kicad_pcb]
2024-05-31 adjust horizontal matrix row traces location
    [hmkb64alps.kicad_pcb]
2024-05-31 roughly position mcu and sourrounding components
    Also change to different usbc footprint
    [hmkb64alps-matrix.kicad_sch, hmkb64alps.kicad_pcb, hmkb64alps.kicad_sch]
2024-06-01 add and switch to yet a different usb-c connector
    also prepare a nicer symbol and clean up libraries
    [hmkb64alps.kicad_sch]
2024-06-01 set outline and fix position of mcu, connectors etc.
    next step is routing the rows/column connections to mcu
    [hmkb64alps.kicad_pcb]
2024-06-01 begin project for prototype pcb (less keys)
    [numblock-matrix.kicad_sch, test_numblock_pcb.kicad_pcb, test_numblock_pcb.kicad_sch]
2024-06-01 update switch footprint submodule to be my fork of the repo
2024-06-01 comment on footprint libraries
2024-06-01 add freecad file for plate (first test, not final at all)
    [plate_merged.FCStd]
2024-06-02 place most components on prototype numblock board
    [test_numblock_pcb.kicad_pcb]
2024-06-02 adjust lower edge cut position for more clearance to stabilizer holes
    [hmkb64alps.kicad_pcb]
2024-06-08 complete the prototype numpad pcb
    [test_numblock_pcb.kicad_pcb, test_numblock_pcb.kicad_sch]
2024-06-16 add bom related tables
    [2024-06-08T101504.csv, test_numblock_pcb.csv]
2024-06-16 add updated digikey parts list
    [2024-06-08T101504.csv, 2024-06-16T081901.csv]
2024-06-16 rename digikey parts csv
    [digikey_parts.csv]
2024-06-16 update list to actually ordered parts
    [digikey_parts.csv]
2024-06-16 update some bom things
    not what I actually ordered for the most part, number of components is
    may differ.
    [test_numblock_pcb.csv]
2024-06-16 add list of parts ordered from digikey
    [digikey_parts.csv, digikey_parts_ordered.csv]
2024-06-30 change hmkb64 -> hmkb65
    I just typoed in the very beginning and never came around to fix it.
    [hmkb65alps-matrix.kicad_sch, hmkb65alps.kicad_pcb, hmkb65alps.kicad_sch]
2024-06-30 fix absolute path to footprint library
2024-06-30 create project for plate pcb and import outline from dxf
    [plate.kicad_pcb, plate.kicad_sch, plate_merged.dxf]
2024-07-01 notes on keyboard plate
2024-07-02 route and assign all rows/columns of the matrix
    also add some more vias where found neccessary
    [hmkb65alps.kicad_pcb, hmkb65alps.kicad_sch]
2024-07-02 add vias around outline
    [hmkb65alps.kicad_pcb]
2024-07-02 add stitching vias
    [hmkb65alps.kicad_pcb]
2024-07-03 place some more stiching vias where it appeared reasonable
    [hmkb65alps.kicad_pcb]
2024-07-14 come up with a plate that "should" work
    [plate.kicad_pcb]
2024-07-14 adjust position of reset switch to line up with hole in case
2024-07-14 move components on front side where they would have interfered with switches
2024-07-14 add custom stuff on silkscreen
2024-07-14 move not so nice looking trace
2024-07-14 add some graphics to maybe put on silkscreen because why not
2024-07-14 adjust programming header silkscreen and add email
2024-07-15 stitch planes because why not and reduce copper to edge clearance
    [plate.kicad_pcb, plate.kicad_sch]
2024-07-15 further reduce copper to edge clearance
    [plate.kicad_pcb]
2024-07-15 check DRC/ERCs and fix minor errors+warnings in ERC
    [hmkb65alps-matrix.kicad_sch, hmkb65alps.kicad_sch]
2024-07-15 revert to branch with soldermask over via annuals on top layer
2024-07-15 adjust footprint submodule to include 3d models
    the main branch did not yet have re-generated footprints that point to
    the 3d models.
2024-07-15 decided against using footprints with no mask cutouts on top layer
    There is no solder mask over the holes and I'm not so sure if that could
    mean that the manufacturers will just put the mask over the hole as with
    a tented via, which would be bad. So I stick with the exposed pads on
    the front which I know work fine.
2024-07-15 add basic kibot config for pcb
2024-07-20 create plate and draw up simple case for numblock in freecad
    [test_numblock_case.FCStd, test_numblock_plate.kicad_pcb, test_numblock_plate.kicad_sch]
2025-08-09 Update PCB files to v9
    [hmkb65alps-matrix.kicad_sch, hmkb65alps.kicad_sch]
2025-08-09 Update plate files to v9
    [plate.kicad_pcb, plate.kicad_sch]
